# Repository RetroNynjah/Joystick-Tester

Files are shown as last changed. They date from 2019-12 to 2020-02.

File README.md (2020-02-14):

# Retro Ninja Joystick-Tester
 Tester for 9-pin Atari and Commodore compatible joysticks.
 
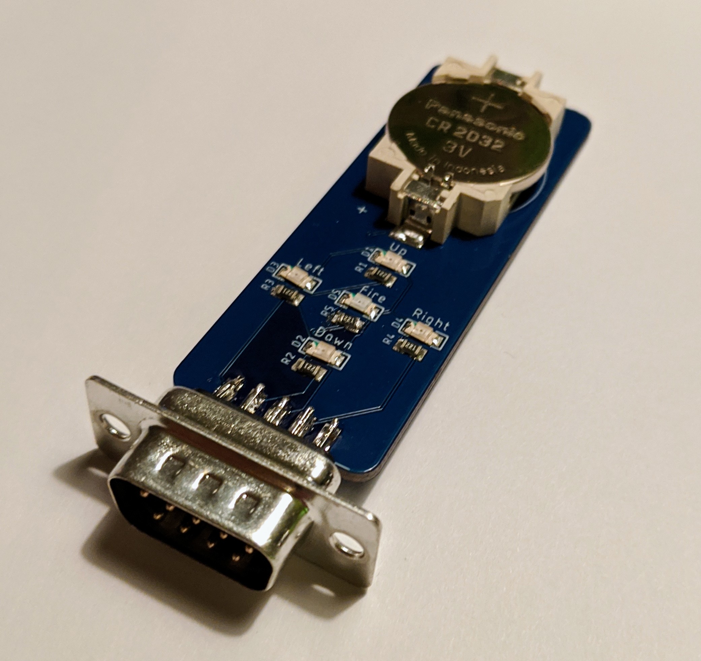
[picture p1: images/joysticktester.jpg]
 
 
  
 
## BOM
 |Component|Pcs |Names|Comment|
 |:--------|---:|:---|:------|
 | CR2032 coin cell holder | 1 | BT1 | 30mm SMD or 20mm throuh-hole. Digikey BU2032SM-BT-GTR, BS-7-ND or similar|
 | 1206 SMD red LED | 1 | D5 | |
 | 1206 SMD green LED | 4 | D1, D2, D3, D4 | |
 | 0805 SMD resistor 220Ω | 5 | R1, R2, R3, R4, R5 ||
 | DE-9M 9-pin male D-sub connector | 1 | X1 |straight connectors or solder cups |

Retro Ninja

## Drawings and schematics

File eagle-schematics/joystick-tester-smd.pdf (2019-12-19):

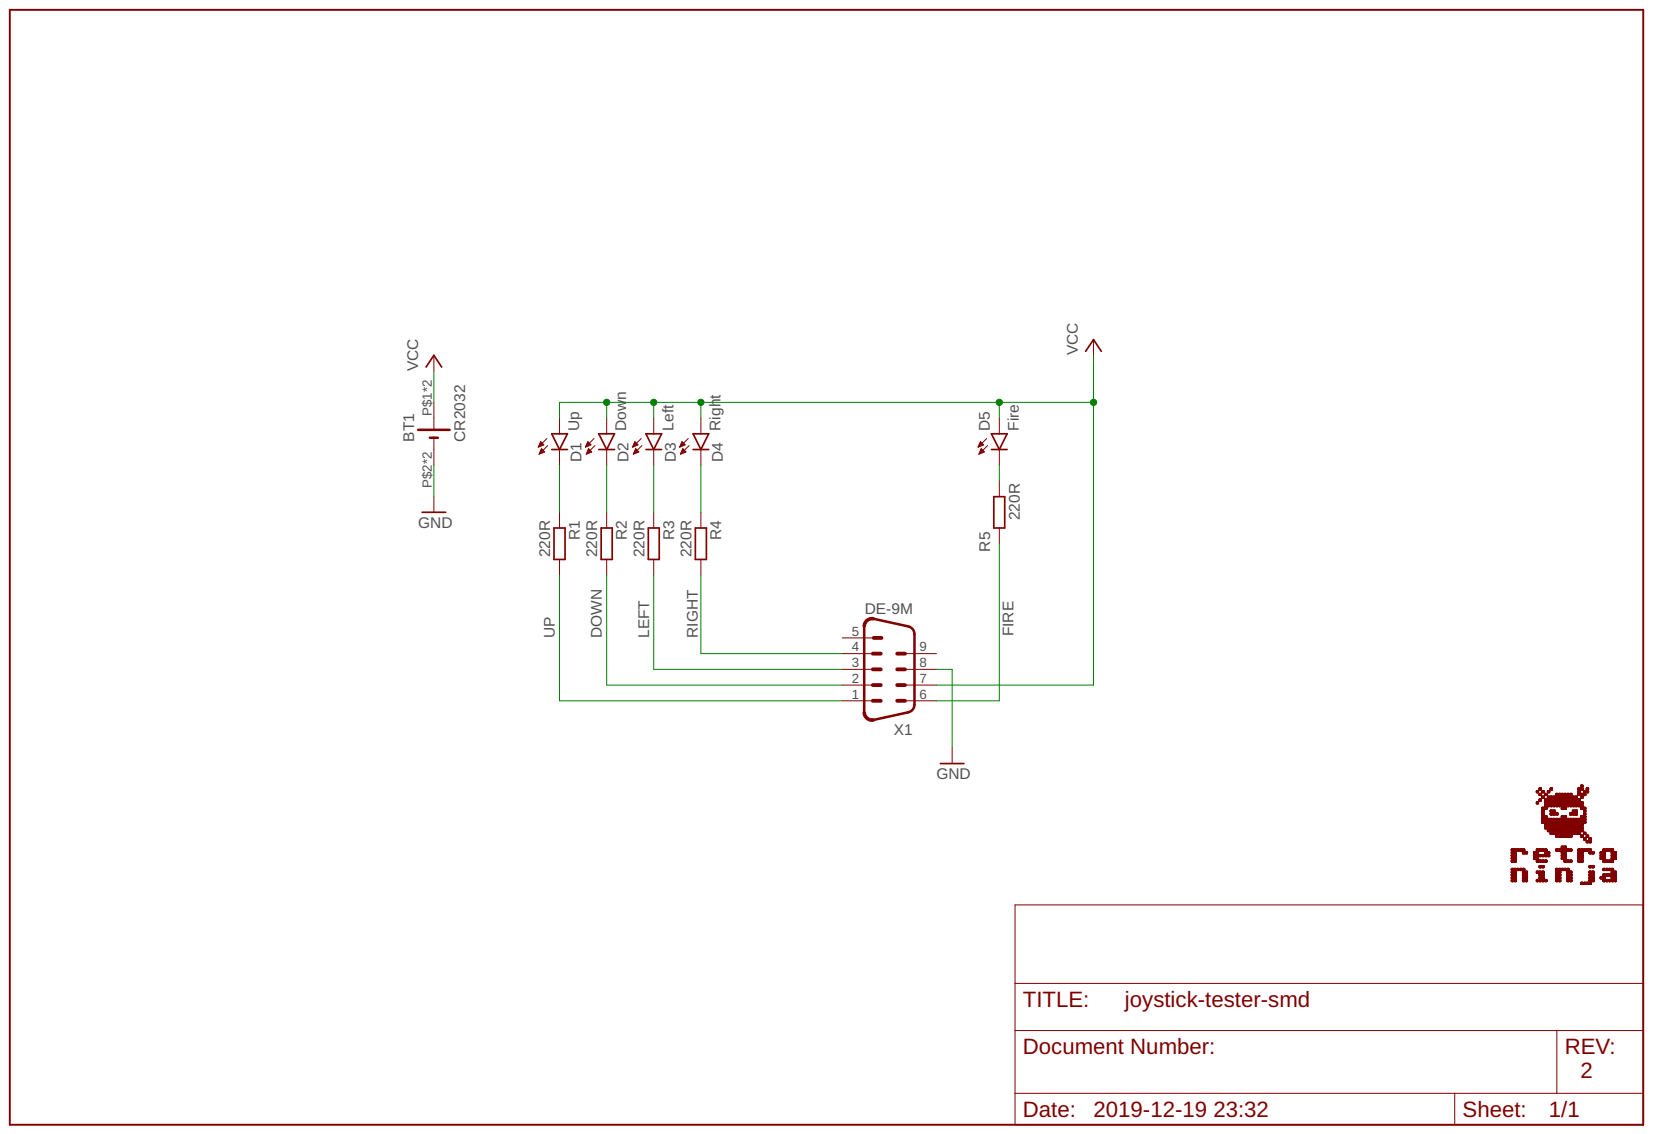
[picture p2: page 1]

Document Number: | REV: 2

Date: 2019-12-19 23:32 | Sheet: 1/1

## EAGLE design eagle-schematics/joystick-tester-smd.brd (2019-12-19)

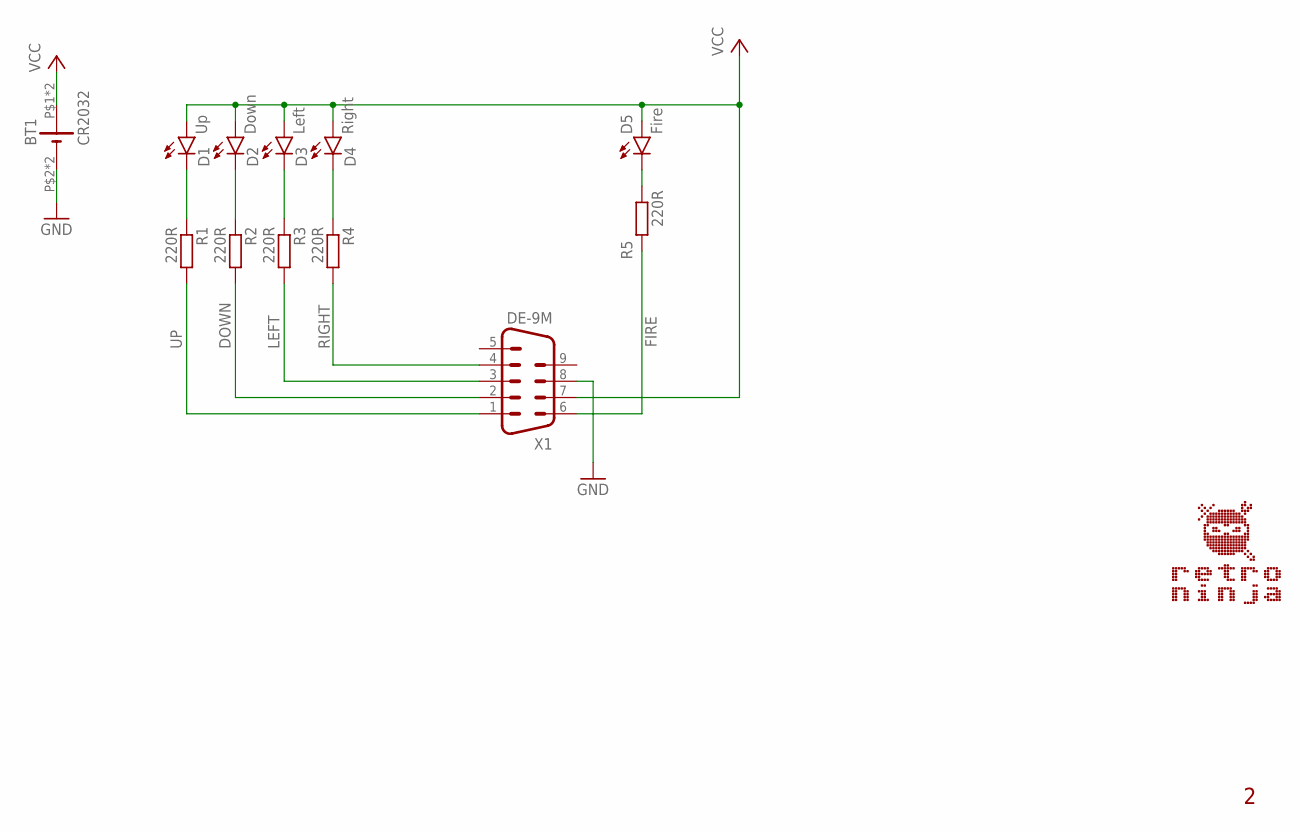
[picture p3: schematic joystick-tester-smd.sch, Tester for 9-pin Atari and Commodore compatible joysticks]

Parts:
BT1: CR2032; CR2032_2P30SMD_20MM_COMBO
D1: Up; LED-1206
D2: Down; LED-1206
D3: Left; LED-1206
D4: Right; LED-1206
D5: Fire; LED-1206
R1, R2, R3, R4, R5: 220R; M0805
X1: DE-9M; M09D

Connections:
DOWN: R2.2, X1.2
FIRE: R5.1, X1.6
GND: BT1.P$2 (-), BT1.P$4 (-), X1.8
LEFT: R3.2, X1.3
unnamed: D4.C, R4.1
unnamed: D5.C, R5.2
unnamed: D1.C, R1.1
unnamed: D2.C, R2.1
unnamed: D3.C, R3.1
RIGHT: R4.2, X1.4
UP: R1.2, X1.1
VCC: BT1.P$1 (+), BT1.P$3 (+), D1.A, D2.A, D3.A, D4.A, D5.A, X1.7

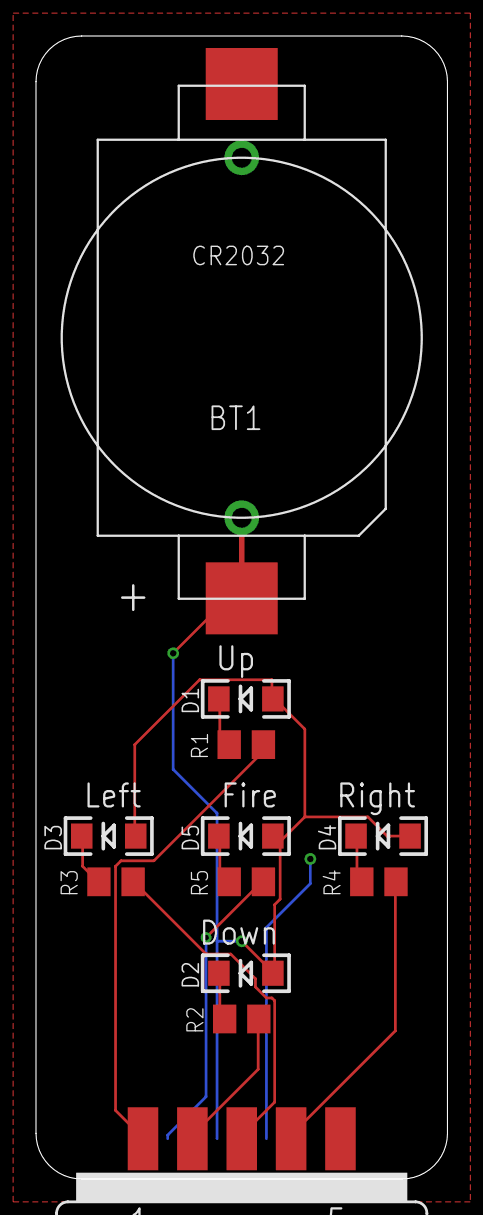
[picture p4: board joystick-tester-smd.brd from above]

Board: 2 copper layers, 22.9 x 63.5 mm, 13 parts (1 on the bottom side), 12 nets.

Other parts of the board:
U$2: OSHW_8MM

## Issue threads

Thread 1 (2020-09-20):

Add a second fire button!

danko79, 2020-09-20:
Hi,I've been looking for this for some time! but can you make a version by adding the second fire button for Amiga?

RetroNynjah, 2020-09-20:
The second button for the Amiga seems to be using pin 9 which is also used as one of the axes for paddles. I have an older version where I tested LEDs for pin 5 and pin 9 as a way to test paddles. Didn't work so I removed them to simplify the board.
Guess those would work for your second button though.
I have a few left from my first run. Do you need to manufacture them or do you need just one board?

danko79, 2020-09-20:
Hi,i need a one PCBs from you;
Amiga external floppy adapter
Amiga 500 ROM Adapter x2
Joystick-Tester
Do you have for sale?

RetroNynjah, 2020-09-20:
I have some extra boards of all of those that I can send you.
Email me at retroninja_at_hofnet.com

danko79, 2024-10-15:
Hi, reopen this, do you share a gerber for the Rev. 1?

Closed 2024-10-17.

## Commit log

2019-12-19 First version
    [joystick-tester-smd.brd, joystick-tester-smd.sch]
2019-12-19 Updated battery layout
    [joystick-tester-smd.brd, joystick-tester-smd.sch]
2019-12-19 Update README.md
    BOM updated
2019-12-19 Update schematics
    [joystick-tester-smd.brd, joystick-tester-smd.sch]
2019-12-19 Update gerbers

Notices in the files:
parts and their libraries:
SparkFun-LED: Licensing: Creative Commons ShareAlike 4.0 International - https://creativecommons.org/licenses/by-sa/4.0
